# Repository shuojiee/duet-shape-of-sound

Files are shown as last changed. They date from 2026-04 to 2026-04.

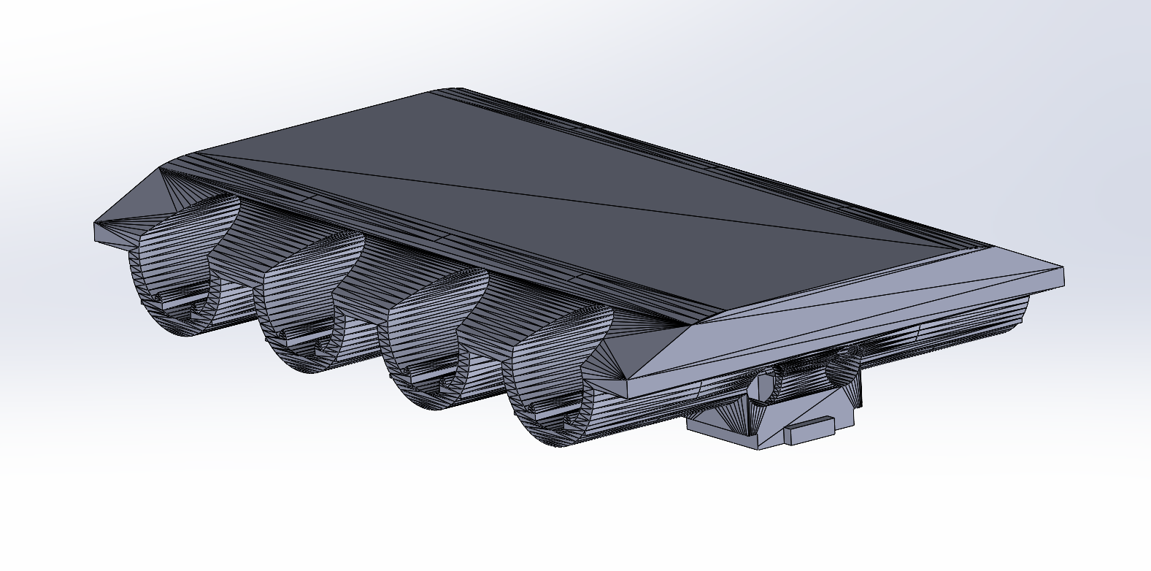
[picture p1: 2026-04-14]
hardware/sensor cover CAD/sensor_cover.png

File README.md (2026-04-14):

# Duet: Shape of Sound

**Duet** is an interactive, 2-player marble instrument designed for musical conversation. As players roll colored marbles down mirrored tracks, sensors trigger unique melodic responses. This shared dialogue explores the intersection of physical movement and sound, allowing two people to "speak" to one another through a generative soundscape.

🔗 **[Project Website & Full Documentation](https://zhengboon.github.io/Shape-Of-Sound/)**

---

## 📂 Repository Structure

*   **/audio**: The sound library (WAV/MP3) and the SD card configuration guide.
*   **/docs**: Comprehensive [User Guide](./docs/User_Guide.md) and [Developer Guide](./docs/Developer_Guide.md).
*   **/firmware**: 
    *   `duet/`: The main production software.
    *   `calibration/`: Interactive tool for hard-coding sensor values.
    *   `debug/`: Real-time serial monitoring of sensor data.
*   **/hardware**: 
    *   `electronics/`: PCB designs and wiring schematics (PDF).
    *   `sensor cover CAD/`: 3D models in SolidWorks (.SLDPRT), .STEP, and .STL formats.
*   **LICENSE**: MIT License.

---

## 🚀 Quick Start & Audio Calibration

1.  **Hardware:** Connect the Arduino, 4x TCS3200 sensors, and the DFPlayer Mini according to the schematics in `/hardware/electronics`.
2.  **Audio:** Load the files in `/audio` onto a FAT32 formatted SD card.
3.  **Upload:** Flash `duet.ino` to the Arduino.
4.  **Calibration:** Upon power-up, the system enters an **Audio-Guided Calibration** phase:
    *   **3-Note Melody:** System Start.
    *   **2-Note Tone:** Place white marbles at all sensor gates now.
    *   **1-Note Tone:** System is recording White levels.
    *   **2-Note Tone:** Remove marbles (or replace with black samples).
    *   **1-Note Tone:** System is recording Black levels.
    *   **3-Note Melody:** Calibration Complete. Start your duet!

---

## 🛠 Technical Features

*   **Conversational Logic:** A split-track architecture designed for non-verbal dialogue between two participants.
*   **Robust Signal Processing:** Implements rolling averages and consecutive confirmation logic to accurately detect marbles at high velocities.
*   **Asynchronous Audio Queue:** A circular buffer manages audio triggers so that simultaneous "replies" from both players are queued and played without overlapping or loss.
*   **Dynamic Lockout:** A software-defined lockout prevents single marbles from double-triggering notes, ensuring a clean musical experience.

---

## 🤝 Handoff Note
This repository serves as a complete archive for the Duet project. It includes all firmware, mechanical designs, and assets required to replicate or iterate on the instrument. Future developers should consult the **Developer Guide** in the `/docs` folder for details on the signal processing pipeline and calibration tuning.

---
**Developed by:** [Zheng Boon](https://zhengboon.github.io/Shape-Of-Sound/)  
**License:** MIT

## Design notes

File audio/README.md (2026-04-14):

# SD Card Setup

To make the audio work with the DFPlayer Mini and the `duet.ino` code, follow these rules:

## 1. SD Card Formatting
*   The SD card must be formatted to **FAT32**.
*   It is recommended to use a card 32GB or smaller.

## 2. File Structure
The code uses the `play()` function, which usually looks for files in the **root** of the SD card or in a folder named **mp3**. 

**Current Mapping in `duet.ino`:**
*   Tracks 2, 3, 4: Startup & Calibration Cues
*   Tracks 5, 6, 7, 8: Calibration Prompts
*   Tracks 18 - 33: Musical notes for Sensor Gates 1-4

## 3. Filename Convention
Ensure your files are named with four-digit prefixes so the DFPlayer can index them correctly:
*   `0002.mp3`
*   `0018.mp3`
*   ...etc.

*Note: If you add new files, the physical order in which you copy them to the SD card can sometimes affect the playback order on the DFPlayer Mini. It is best to format the card and copy all files onto it in one go.*

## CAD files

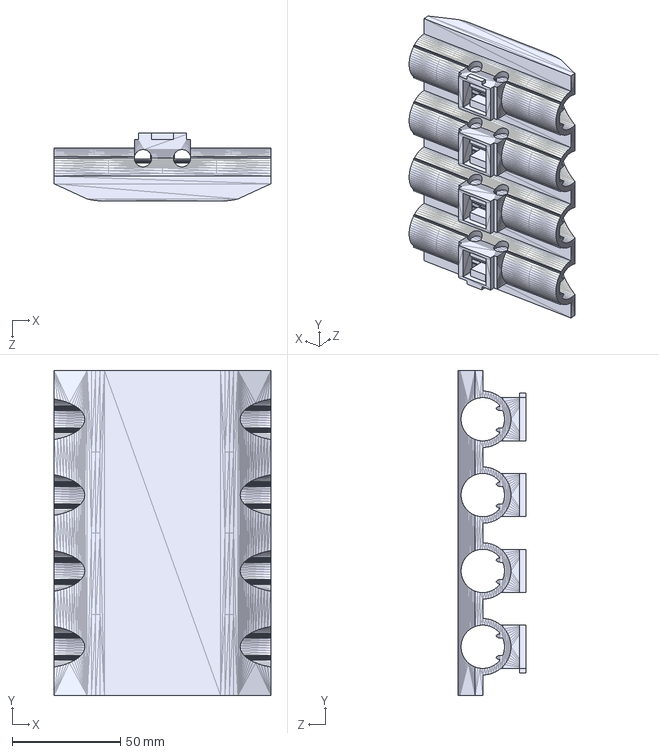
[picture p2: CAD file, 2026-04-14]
hardware/sensor cover CAD/sensor_cover.STEP
100.0 x 150.0 x 31.5 mm

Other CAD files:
hardware/sensor cover CAD/sensor_cover.STL

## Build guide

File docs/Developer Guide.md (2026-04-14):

# Developer's Guide: Duet Logic & Tools

This guide explains the software architecture and the specialized tools provided for maintaining and improving the Duet system.

## 🛠 Developer Toolset
While the main `duet.ino` file is the production software, this repository includes two specialized scripts for development:

1.  **`calibration.ino`**: Use this to generate hard-coded calibration values. If the instrument will be in a permanent installation with fixed lighting, run this script, copy the Serial output, and paste it into the `CALIBRATION VALUES` fallback defaults in `duet.ino`.
2.  **`debug.ino`**: Use this to troubleshoot sensor hardware. It prints raw pulse widths, mapped RGB values, and the current classification to the Serial Monitor (9600 baud) every 500ms.

## 📡 Signal Processing Pipeline
The system uses a three-stage pipeline to handle fast-moving marbles:
*   **Robust Sampling (`robustRead`):** Takes 5 samples and discards timeouts (`0` values) to filter electrical noise.
*   **Rolling Averages:** Smooths raw data through a 5-sample circular buffer to account for the marble's curved, reflective surface.
*   **Consecutive Confirmation:** A color must be detected `3` times in a row before a note is triggered to prevent "ghost" sounds.

## 🎹 Musical Dialogue Logic
### Audio Queueing
Because two players may trigger notes simultaneously, the system uses an **Asynchronous Audio Queue**. 
*   Detected notes are added to an 8-slot buffer.
*   `serviceQueue()` monitors the DFPlayer’s `busyPin` (A2).
*   Tracks are played back-to-back as the player becomes free, ensuring no "responses" in the conversation are lost.

### Dynamic Lockout
To prevent a single marble from "double-triggering" a note, the sensor enters a lockout state immediately upon detection. It only resets once `avgVals` drops below the `noColourThresh`, signaling that the marble has physically exited the sensor gate.

## ⚙️ Key Constants
*   `HIGH_FRACTION (0.75)`: Brightness threshold for color detection.
*   `GAP_FRACTION (0.15)`: Necessary separation between color channels for classification.
*   `SENSOR_SETTLE_US (200)`: Delay to stabilize sensors after switching shared pins.

---
**Original Developer:** Zheng Boon  
**Project:** Duet (Shape of Sound)

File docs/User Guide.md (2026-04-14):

# User Guide: Duet

## 🎶 The Concept
**Duet** is an interactive, two-player musical instrument designed for non-verbal conversation. By rolling colored marbles down a split-track system, players trigger melodic responses. The instrument is a dialogue: one person "speaks" with a marble, and the other "responds."

## 🚀 How to Use (Audio-Guided Startup)
When you power on the instrument, it will guide you through a calibration phase using a series of tones. **Follow these steps precisely to ensure the instrument can "see" your marbles correctly.**

| Step | Audio Cue | Action Required |
|:--- |:--- |:--- |
| 1 | **3-Note Melody** | System is starting up. |
| 2 | *5s Silence* | Prepare your white marbles. |
| 3 | **2-Note Tone** | **Place a White Marble** in front of every sensor. |
| 4 | *10s Silence* | Wait for the sensors to prepare. |
| 5 | **1-Note Tone** | **Do not touch.** System is recording White values. |
| 6 | *1.5s Silence* | Preparing for next step. |
| 7 | **2-Note Tone** | **Remove White Marbles** (Leave gates empty or use Black). |
| 8 | *10s Silence* | Wait for the sensors to prepare. |
| 9 | **1-Note Tone** | **Do not touch.** System is recording Black values. |
| 10 | *1.5s Silence* | Processing thresholds. |
| 11 | **3-Note Melody** | **Calibration Complete.** You may now begin the duet! |

## ⚖️ Troubleshooting
If the colors are not triggering correctly during play, restart the device and repeat the calibration sequence. Ensure that no bright sunlight is hitting the sensors directly.

---
**Project Website:** [Shape of Sound](https://zhengboon.github.io/Shape-Of-Sound/)

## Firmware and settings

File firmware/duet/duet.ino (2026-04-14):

#include <SoftwareSerial.h>
#include <DFRobotDFPlayerMini.h>

// ---- Sensor count ----
const int NUM_SENSORS = 4;

// ---- Color Definitions (MOVED TO TOP) ----
const int COL_PINK   = 0;
const int COL_BLUE   = 1;
const int COL_GREEN  = 2;
const int COL_YELLOW = 3;
const int COL_NONE   = -1;

// =====================================================
// CALIBRATION VALUES — fallback defaults.
// =====================================================
unsigned long redMin[NUM_SENSORS]   = {0, 0, 502, 754};
unsigned long greenMin[NUM_SENSORS] = {0, 0, 1297, 2131};
unsigned long blueMin[NUM_SENSORS]  = {0, 0, 2160, 1132};

unsigned long redMax[NUM_SENSORS]   = {0, 0, 558, 1443};
unsigned long greenMax[NUM_SENSORS] = {0, 0, 1076, 1264};
unsigned long blueMax[NUM_SENSORS]  = {0, 0, 2182, 1459};

// =====================================================
// CLASSIFICATION THRESHOLDS
// =====================================================
const float HIGH_FRACTION      = 0.75;
const float GAP_FRACTION       = 0.15;
const float NO_COLOUR_FRACTION = 0.30;

// ---- DFPlayer ----
SoftwareSerial mySerial(A0, A1);
DFRobotDFPlayerMini myDFPlayer;
const int busyPin   = A2;
const int DF_VOLUME = 25;

// ---- Pin Assignments ----
const int S2_PINS[NUM_SENSORS]  = {5, 7, 9, 11};
const int S3_PINS[NUM_SENSORS]  = {6, 8, 10, 12};
const int OUT_PINS[NUM_SENSORS] = {2, 3, 4, 13};

// ---- RGB Storage ----
int redVals[NUM_SENSORS]   = {0};
int greenVals[NUM_SENSORS] = {0};
int blueVals[NUM_SENSORS]  = {0};
int avgVals[NUM_SENSORS]   = {0};

// ---- Rolling Average Buffers ----
const int ROLLING_SIZE = 5;
int rollingRed[NUM_SENSORS][ROLLING_SIZE]   = {0};
int rollingGreen[NUM_SENSORS][ROLLING_SIZE] = {0};
int rollingBlue[NUM_SENSORS][ROLLING_SIZE]  = {0};
int rollingIdx[NUM_SENSORS]                 = {0};

// ---- Consecutive Confirmation ----
const int CONFIRM_COUNT = 3; 
int confirmColour[NUM_SENSORS]; // Initialized in setup()
int confirmStreak[NUM_SENSORS] = {0};         

// ---- Classification Threshold Storage ----
int highThresh[NUM_SENSORS]     = {0};
int gapThresh[NUM_SENSORS]      = {0};
int noColourThresh[NUM_SENSORS] = {0};

// ---- Track Lookup Table ----
const int trackTable[NUM_SENSORS][4] = {
  {18, 22, 26, 30},
  {19, 23, 27, 31},
  {20, 24, 28, 32},
  {21, 25, 29, 33},
};

// ---- Dynamic Lockout ----
bool inLockout[NUM_SENSORS] = {false};

// ---- Audio Queue ----
const int QUEUE_SIZE = 8;
int audioQueue[QUEUE_SIZE] = {0};
int queueHead = 0;
int queueTail = 0;

// ---- Pulse Timeout ----
const unsigned long PULSE_TIMEOUT = 5000;
const int SENSOR_SETTLE_US = 200;
const int CAL_SAMPLES  = 15; 
const int LIVE_SAMPLES = 5;  

// ---- Forward Declarations ----
void calibrateSensors();
void computeThresholds();
void readColour(int sensorIdx);
int classifyColour(int i);
void enqueueTrack(int track);
void serviceQueue();
unsigned long readPulseWidth(int sensorIdx, bool s2Val, bool s3Val);
unsigned long stableRead(int i, bool s2, bool s3, int samples);
unsigned long robustRead(int i, bool s2, bool s3, int samples);

void setup() {
  mySerial.begin(9600);
  pinMode(busyPin, INPUT);
  
  if (!myDFPlayer.begin(mySerial)) {
    while(true); // Halt if DFPlayer not found
  }
  
  myDFPlayer.volume(DF_VOLUME);

  // Properly initialize arrays
  for (int i = 0; i < NUM_SENSORS; i++) {
    pinMode(S2_PINS[i], OUTPUT);
    pinMode(S3_PINS[i], OUTPUT);
    pinMode(OUT_PINS[i], INPUT);
    confirmColour[i] = COL_NONE;
    confirmStreak[i] = 0;
    inLockout[i] = false;
  }

  calibrateSensors();
  computeThresholds();
}

void loop() {
  for (int i = 0; i < NUM_SENSORS; i++) {
    delayMicroseconds(SENSOR_SETTLE_US);
    readColour(i);
  }

  for (int i = 0; i < NUM_SENSORS; i++) {
    int colourIdx = classifyColour(i);

    if (inLockout[i]) {
      if (avgVals[i] < noColourThresh[i]) {
        inLockout[i] = false;
        confirmStreak[i]  = 0;
        confirmColour[i]  = COL_NONE;
      }
      continue; 
    }

    if (colourIdx == COL_NONE) {
      confirmStreak[i] = 0;
      confirmColour[i] = COL_NONE;
      continue;
    }

    if (colourIdx == confirmColour[i]) {
      confirmStreak[i]++;
    } else {
      confirmColour[i] = colourIdx;
      confirmStreak[i] = 1;
    }

    if (confirmStreak[i] >= CONFIRM_COUNT) {
      enqueueTrack(trackTable[i][colourIdx]);
      inLockout[i]     = true;
      confirmStreak[i] = 0;
      confirmColour[i] = COL_NONE;
    }
  }

  serviceQueue(); 
  delay(10);
}

void calibrateSensors() {
  myDFPlayer.play(2); delay(750);
  myDFPlayer.play(2); delay(750);
  myDFPlayer.play(18); delay(5000);

  myDFPlayer.play(2); delay(750);
  myDFPlayer.play(2); delay(10000);

  myDFPlayer.play(2);
  for (int i = 0; i < NUM_SENSORS; i++) {
    redMin[i]   = robustRead(i, LOW,  LOW,  CAL_SAMPLES);
    greenMin[i] = robustRead(i, HIGH, HIGH, CAL_SAMPLES);
    blueMin[i]  = robustRead(i, LOW,  HIGH, CAL_SAMPLES);
  }
  delay(1500);

  myDFPlayer.play(5); delay(750);
  myDFPlayer.play(5); delay(10000);

  myDFPlayer.play(5);   
  for (int i = 0; i < NUM_SENSORS; i++) {
    redMax[i]   = robustRead(i, LOW,  LOW,  CAL_SAMPLES);
    greenMax[i] = robustRead(i, HIGH, HIGH, CAL_SAMPLES);
    blueMax[i]  = robustRead(i, LOW,  HIGH, CAL_SAMPLES);
  }
  delay(1500);

  myDFPlayer.play(7); delay(750);
  myDFPlayer.play(8); delay(750);
  myDFPlayer.play(32);
}

void computeThresholds() {
  for (int i = 0; i < NUM_SENSORS; i++) {
    highThresh[i]     = (int)(255 * HIGH_FRACTION);
    gapThresh[i]      = (int)(255 * GAP_FRACTION);
    noColourThresh[i] = (int)(255 * NO_COLOUR_FRACTION);
  }
}

unsigned long readPulseWidth(int sensorIdx, bool s2Val, bool s3Val) {
  digitalWrite(S2_PINS[sensorIdx], s2Val);
  digitalWrite(S3_PINS[sensorIdx], s3Val);
  delayMicroseconds(50);
  return pulseIn(OUT_PINS[sensorIdx], LOW, PULSE_TIMEOUT);
}

unsigned long robustRead(int i, bool s2, bool s3, int samples) {
  unsigned long sum = 0;
  int validSamples = 0;
  for (int n = 0; n < samples; n++) {
    unsigned long val = readPulseWidth(i, s2, s3);
    if(val > 0) {
        sum += val;
        validSamples++;
    }
    delay(2);
  }
  return (validSamples > 0) ? (sum / validSamples) : 0;
}

void readColour(int sensorIdx) {
  int r = constrain(map(robustRead(sensorIdx, LOW,  LOW,  LIVE_SAMPLES), redMin[sensorIdx],   redMax[sensorIdx],   255, 0), 0, 255);
  int g = constrain(map(robustRead(sensorIdx, HIGH, HIGH, LIVE_SAMPLES), greenMin[sensorIdx], greenMax[sensorIdx], 255, 0), 0, 255);
  int b = constrain(map(robustRead(sensorIdx, LOW,  HIGH, LIVE_SAMPLES), blueMin[sensorIdx],  blueMax[sensorIdx],  255, 0), 0, 255);

  int idx = rollingIdx[sensorIdx];
  rollingRed[sensorIdx][idx]   = r;
  rollingGreen[sensorIdx][idx] = g;
  rollingBlue[sensorIdx][idx]  = b;
  rollingIdx[sensorIdx] = (idx + 1) % ROLLING_SIZE;

  long sumR = 0, sumG = 0, sumB = 0;
  for (int n = 0; n < ROLLING_SIZE; n++) {
    sumR += rollingRed[sensorIdx][n];
    sumG += rollingGreen[sensorIdx][n];
    sumB += rollingBlue[sensorIdx][n];
  }
  redVals[sensorIdx]   = sumR / ROLLING_SIZE;
  greenVals[sensorIdx] = sumG / ROLLING_SIZE;
  blueVals[sensorIdx]  = sumB / ROLLING_SIZE;
  avgVals[sensorIdx]   = (redVals[sensorIdx] + greenVals[sensorIdx] + blueVals[sensorIdx]) / 3;
}

int classifyColour(int i) {
  int r = redVals[i], g = greenVals[i], b = blueVals[i];
  if (avgVals[i] < noColourThresh[i]) return COL_NONE;
  if (b > r && b > g && (b - r) > gapThresh[i]) return COL_BLUE;
  if (g > r && g > b && r < highThresh[i])      return COL_GREEN;
  if (r > highThresh[i] && g > highThresh[i] && b < r) return COL_YELLOW;
  if (r > g && r > b)                           return COL_PINK;
  return COL_NONE;
}

void enqueueTrack(int track) {
  int nextTail = (queueTail + 1) % QUEUE_SIZE;
  if (nextTail == queueHead) return; 
  audioQueue[queueTail] = track;
  queueTail = nextTail;
}

void serviceQueue() {
  if (queueHead == queueTail) return;           
  if (digitalRead(busyPin) == LOW) return;      
  myDFPlayer.play(audioQueue[queueHead]);
  queueHead = (queueHead + 1) % QUEUE_SIZE;
}

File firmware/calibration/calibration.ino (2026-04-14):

// Colour sensors pin assignments
const int NUM_SENSORS = 4;
const int S2_PINS[NUM_SENSORS]  = {5, 7, 9, 11};
const int S3_PINS[NUM_SENSORS]  = {6, 8, 10, 12};
const int OUT_PINS[NUM_SENSORS] = {2, 3, 4, 13};

const unsigned long PULSE_TIMEOUT = 5000;

// Store RGB values
unsigned long redVals[NUM_SENSORS] = {0};
unsigned long greenVals[NUM_SENSORS] = {0};
unsigned long blueVals[NUM_SENSORS] = {0};

// Store calibration RGB values
unsigned long redMin[NUM_SENSORS] = {0};
unsigned long greenMin[NUM_SENSORS] = {0};
unsigned long blueMin[NUM_SENSORS] = {0};
unsigned long redMax[NUM_SENSORS] = {0};
unsigned long greenMax[NUM_SENSORS] = {0};
unsigned long blueMax[NUM_SENSORS] = {0};

void setup() {
  // baud rate 11520
  Serial.begin(115200);

/* 
  set S2 & S3 pins of each sensor as output
  set OUT pins of each sensor as input
*/
  for (int i = 0; i < NUM_SENSORS; i++) {
    pinMode(S2_PINS[i], OUTPUT);
    pinMode(S3_PINS[i], OUTPUT);
    pinMode(OUT_PINS[i], INPUT);
  }
}

void loop() {
/*
  calibrate and print calibration values
*/
  calibrateSensors();
  printVals();
}

/*
  set S2 & S3 pins HIGH or LOW to read each RGB value:
  (LOW, LOW)    --> Red
  (HIGH, HIGH)  --> Green
  (LOW, HIGH)   --> Blue
  (HIGH, LOW)   --> Clear (No Filter)

  measure pulse width (frequency) in microseconds to determine light intensity
*/
unsigned long readPulseWidth(int sensorIdx, bool s2Val, bool s3Val) {
  
  digitalWrite(S2_PINS[sensorIdx], s2Val);
  digitalWrite(S3_PINS[sensorIdx], s3Val);
  
  delayMicroseconds(100);

  // pulseIn() starts reading pulse width after pin goes LOW
  return pulseIn(OUT_PINS[sensorIdx], LOW, PULSE_TIMEOUT);
}

unsigned long stableRead(int i, bool s2, bool s3) {
  unsigned long sum = 0;

  for (int n = 0; n < 5; n++) {
    sum += readPulseWidth(i, s2, s3);
    delay(10);
  }
  return sum / 5;
}

void calibrateSensors() {
  Serial.println("Calibrating sensors...");

  // WHITE calibration
  Serial.println("Place a WHITE marble in front of every sensor, then press ENTER...");
  while (!Serial.available());
  Serial.read();

  for (int i = 0; i < NUM_SENSORS; i++) {
    redMin[i] = stableRead(i, LOW, LOW);
    greenMin[i] = stableRead(i, HIGH, HIGH);
    blueMin[i] = stableRead(i, LOW, HIGH);

    Serial.print("Sensor "); Serial.print(i); Serial.println(" white calibrated.");
  }

  // BLACK calibration
  Serial.println("Place a BLACK marble in front of every sensor, then press ENTER...");
  while (!Serial.available());
  Serial.read();

  for (int i = 0; i < NUM_SENSORS; i++) {
    redMax[i] = stableRead(i, LOW, LOW);
    greenMax[i] = stableRead(i, HIGH, HIGH);
    blueMax[i] = stableRead(i, LOW, HIGH);

    Serial.print("Sensor "); Serial.print(i); Serial.println(" black calibrated.");
  }

  Serial.println("Calibration complete!");
}

/*
  WHITE values (lower value indicates higher light intensity)
  redMin:   {14, 15, 13, 14}
  greenMin: {13, 13, 10, 15}
  blueMin:  {11, 11, 8, 12}

  BLACK values
  redMax:   {50, 59, 61, 56}
  greenMax: {46, 50, 56, 58}
  blueMax:  {39, 46, 43, 48}
*/
void printVals() {
  Serial.println("\n// ===== PASTE THIS BLOCK INTO duet.ino =====\n");

  Serial.println("// WHITE calibration (min pulse width = brightest)");
  Serial.print("unsigned long redMin[NUM_SENSORS]   = {");
  for (int i = 0; i < NUM_SENSORS; i++) { Serial.print(redMin[i]);   if (i < NUM_SENSORS-1) Serial.print(", "); } Serial.println("};");
  Serial.print("unsigned long greenMin[NUM_SENSORS] = {");
  for (int i = 0; i < NUM_SENSORS; i++) { Serial.print(greenMin[i]); if (i < NUM_SENSORS-1) Serial.print(", "); } Serial.println("};");
  Serial.print("unsigned long blueMin[NUM_SENSORS]  = {");
  for (int i = 0; i < NUM_SENSORS; i++) { Serial.print(blueMin[i]);  if (i < NUM_SENSORS-1) Serial.print(", "); } Serial.println("};");

  Serial.println();

  Serial.println("// BLACK calibration (max pulse width = darkest)");
  Serial.print("unsigned long redMax[NUM_SENSORS]   = {");
  for (int i = 0; i < NUM_SENSORS; i++) { Serial.print(redMax[i]);   if (i < NUM_SENSORS-1) Serial.print(", "); } Serial.println("};");
  Serial.print("unsigned long greenMax[NUM_SENSORS] = {");
  for (int i = 0; i < NUM_SENSORS; i++) { Serial.print(greenMax[i]); if (i < NUM_SENSORS-1) Serial.print(", "); } Serial.println("};");
  Serial.print("unsigned long blueMax[NUM_SENSORS]  = {");
  for (int i = 0; i < NUM_SENSORS; i++) { Serial.print(blueMax[i]);  if (i < NUM_SENSORS-1) Serial.print(", "); } Serial.println("};");

  Serial.println("\n// ===== END PASTE BLOCK =====\n");
}
